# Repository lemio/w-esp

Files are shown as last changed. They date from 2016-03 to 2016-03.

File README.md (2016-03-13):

# w-esp
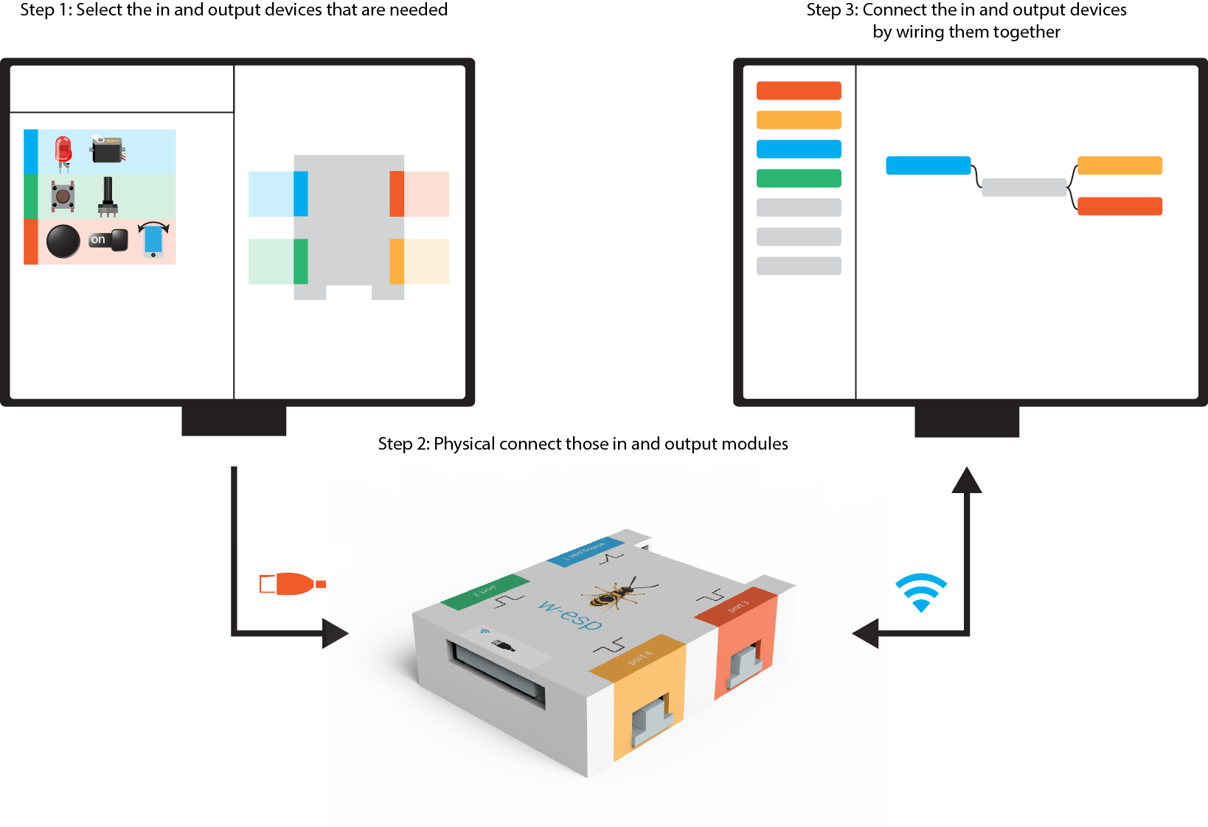
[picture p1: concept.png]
W-esp enable students to play with the internet of things


 The W-esp is a toolkit that enables the first and second year students of secondary education to connect sensors and actuators to the internet and create interactive systems that use the internet of things. This could be for example a locker that is controlled by your mobile phone, a system that prevent your grandmother from sleepwalking, automatically feeds the chickens… the sky is the limit.

The process of building such a system consists of three steps. First the w-esp needs to know which sensors and actuators are connected to the board, by using a drag and drop system [see step 1] the user can drop the in- and output icons on the different ports. After doing that the hardware needs to be physically connected to the w-esp [step 2]. Now the students can open a flow chart programming system based on Node-red(IBM) [step 3] in which they can flows consisting of input blocks, output blocks and processing blocks.

I learned very early the difference between knowing the name of something and knowing something. – R.P. Feynman

In this way the children can learn about programming concepts, without the need to learn difficult syntaxes and languages, they also can use the internet (social media, mobile phone) as in or output and in this way create awesome projects.

#Getting started (software)

* Update the firmware on your w-esp (see the folder final_firmware_esp)
* Put the LUA code on your esp board (see the folder lua_code)
* Donwload node.js https://nodejs.org/en/
* Run node-red (see folder w-esp-node-red)
* Open the chrome app (see folder w-esp-chrome-app)
* Find your IP adress (start; type cmd and press enter) -> type ipconfig in the command line
* Fill in the connection details in the chrome app
* Connect the blocks you want to use
* Hit launch node-red
* Click on the right-top
* Click import from clipboard
* Start playing with node-red

# Getting started hardware

* Getting the parts (see folder hardware)
* Solder or make a breadboard setup for your components
* 3D print a casing (optional)
* print a sticker for the port mapping (optional)

# Future

* Live debugging (in a visual way), the threshold to use the debug function is still to high. Ideally you want to see the messages, and their values flowing through the wires. Also the icons of the sensors/actuators could show their status (in a way that you can really see the servo moving, and the pushbutton being pushed in the software)
* Larger icons and corresponding color in node-red, also connecting the visual styles of node-red and w-esp more. The w-esp software and the node-red software are still two different things, they should merge to one system node-red should also communicate what is connected to the w-esp hardware.
* More decent firmware (native c++), the current firmware is based on LUA, because it was easier to write it in LUA. But when moving to production the firmware should be based on c/c++ because then the hardware could be used optimal and memory issues are history.
* Integration with other (flow chart/data logging) online services, for example If this than that (a cloud service for connecting different application programming interfaces with each other and Thingspeak (data logging service).
* More solid (and less open) course material, teachers want to have something to fall back at. Perhaps this could be in combination with inspiration on different design briefs for the teacher.
* Focus more on how girls relate to this subject, using textiles/more context/less hands-on.
* Try to use the hardware that is already in the school (most physics classes have banana connectors and hardware that can be connected with those banana wires.
* More hardware to connect to the w-esp (and perhaps an advanced toolkit) for example klikaanklikuit remote controlled relays, distance sensors, speakers, light sensor, temperature sensor, touch sensor.
* Running a pilot with different schools to detect practical problems.

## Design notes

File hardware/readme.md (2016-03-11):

#Hardware

##3D printed parts

- bottom_w-esp.stl
- top_w-esp.stl

Those parts are printed in a FabLab in Eindhoven. I also added the source files *.prt the parts are designed in Siemens NX. 

##Casing sticker

This sticker is printed on a laser-jet printer, they are cut with a knife ;)

##Electronics

See the fritzing file for the schematic

(with pricing in euro's, estimate)

| Object 	| EU |
| ---	| --:|
| ESP chip |8,00|
| PCB cost |1,00|
| Connectors |0,80|
| Screw terminals |1,00|
| Casing |5,00|
| servo |3.50|
| led |0,50|
| pushbutton |0,50|
| slider |0,50|
| Packaging |2,00|
| USB cable |1,00|
| Other/unexpected  |2,00|

NodeMCU can for example be found:
* (http://www.ebay.com/sch/i.html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)
* (http://www.dx.com/p/nodemcu-esp8266-esp-12-deleopment-board-lua-wi-fi-module-w-built-in-antennas-385190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)

So in total for less than 30 euro's

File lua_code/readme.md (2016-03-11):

#Lua code

First update the firmware on the ESP chip (see the firmware section), this is needed to make sure there is enough heap space for the program to run.

Open the files in ESPlorer or another LUA editor
https://github.com/4refr0nt/ESPlorer

1. Upload the files to the ESP chip
2. Compile those files (except the conf.lua files)
3. Delete the not compiled versions from the chip (except the conf.lua files)

## Overview of files
### init
(Initializes the program, also makes sure that you can stop the other code from running by connecting pin 4 to the ground)

### start
"start" (requires all the other files, is the main program, it deals with the WIFI, makes all devices are added and keeps the websocket alive, or restarts the connection)

### devices
(Takes care of the devices that are plugged or unplugged in the software, makes sure (PWM) ports are configured in the right way, and sets the triggers for the inputs)

| Type | DeviceType |
| --- | ---:|
| NO_CONNECTION | -1|
| ANALOG_DEVICE | 0|
| ANALOG_OUTPUT | 1|
| DIGITAL_INPUT | 2|
| SERVO_OUTPUT | 3|

**deleteDevice** (port (port on the w-esp 1-4; integer), deviceType (type of device 0-3; integer)

Deletes the device, disable the pwm/trigger/analog behavior

**addDevice** (port (port on the w-esp 1-4; integer), deviceType (type of device 0-3; integer)

Adds the device, enables the pwm/trigger/analog behavior 

**getDevices** ()

Prints the current devices connected to the w-esp in this format:
`DEVICES&1&(P1)&2&(P2)&3&(P3)&4&(P4)&`
where (Px) is replaced with the deviceType

**setDevices** ()

Save the current global ports variable in the devices.conf.lua file

### websocket

**ws_recieve** (conn (.net connection), payload (string))

Handle the recieved messages

**range** (val; integer, max; integer) 

Fit a value within a range from (0 to max)

**ws_begin** (host (domain name or IP string), path (string),port (string))

Start a .net connection with the host

**ws_start** (conn (.net connection), IP (String))

Setup a websocket connection with the conn

**ws_keep_alive** () 

Send ping (keep alive) message; it should give back a pong message (still alive)

**ws_send** (msg) 

Send a websocket message, with a specific content

**ws_close** () 

Close the websocket client

### settings

**changeWifi** (ssid,password)

Change the wifi network and password

**readWifi** ()

Read the current wifi.conf.lua settings and print those (over the serial port) in this format:

`SSID&(x)&PASS&(x)`

**connectWifi** ()

Connect to the selected wifi network

**changeConnection** (host,path,port)

Change the connection details (for the websocket server)

**readConnection** ()

Read the connection details and print those (over the serial port) in this format:

`HOST&(x)&PATH&(x)&PORT&(x)`

**startConnection** ()

Start a connection with the websocket server

**closeConnection** ()

Close the connection with the websocket server (Not implemented)

(All the functions for changing settings from the chrome app, connection and wifi)

## Config files

### wifi.conf.lua

File with the wifi settings, in this format:

```ini
ssid="nameofssid"
password="passwordofssid"```

### connection.conf.lua

File with the server settings, in this format:

```ini
host = "my.web.server.com"
path = "/my/path/for/the/websocket/"
port = 80```

(host could also be an (local) IP adress)

### devices.conf.lua

File with the devices connected to the w-esp, in this format:

```ini
ports = {-1,-1,-1,-1}```

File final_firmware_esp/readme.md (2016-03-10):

If you just want to upload it to the ESP chip:

Use https://github.com/nodemcu/nodemcu-flasher

If you want to create your own firmware:

Built using NodeMCU-build

http://nodemcu-build.com/

Selected modules:
adc, file, gpio, net, node, pwm, tmr, uart, wifi

And choose integer for download

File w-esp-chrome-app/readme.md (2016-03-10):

Go to settings in Google Chrome

Go to extensions

Select Load unpacked extension

-> Select the w-esp-chrome-app folder

When you browse to apps (chrome://apps/ , in my case in the left top corner) the w-esp app should be visible. First connect the w-esp and afterwards start the app. This app uses the Serial port and might not properly close it, so if you want to use ESPlorer afterwards, unplug the w-esp and plug it in. 

The app still needs a lot of documentation and more proper file index...

#references

The design of the components is from fritzing:
Creative Commons Attribution-ShareALike 3.0 Unported

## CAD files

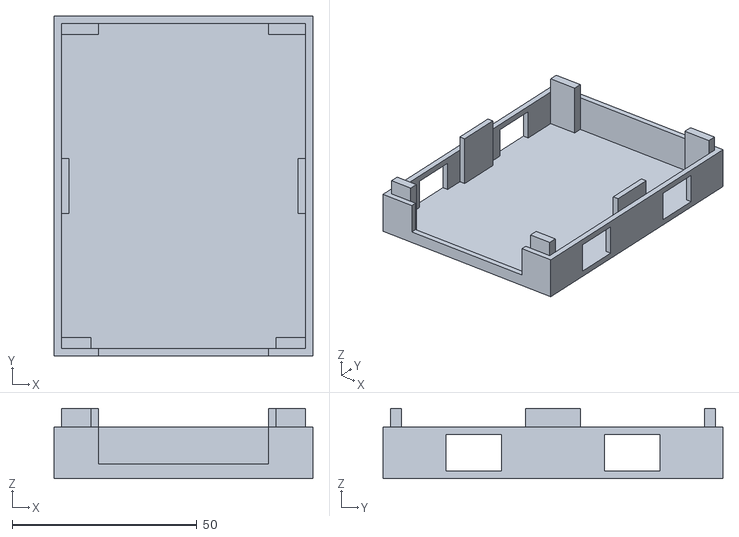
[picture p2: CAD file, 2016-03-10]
hardware/bottom_w-esp.stl
70.0 x 92.0 x 19.0

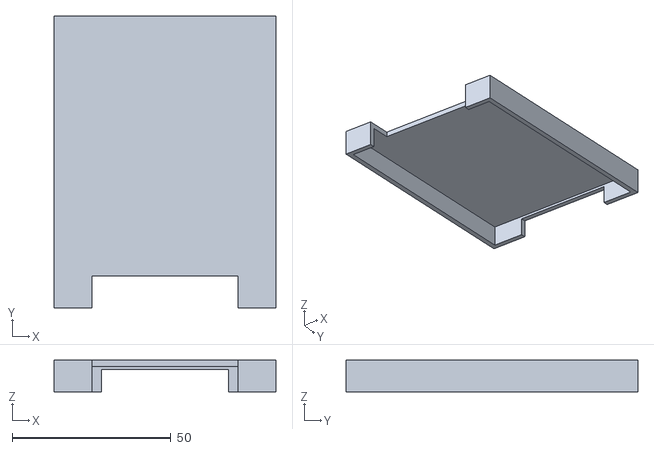
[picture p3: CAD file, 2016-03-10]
hardware/top_w-esp.stl
70.0 x 92.0 x 10.0

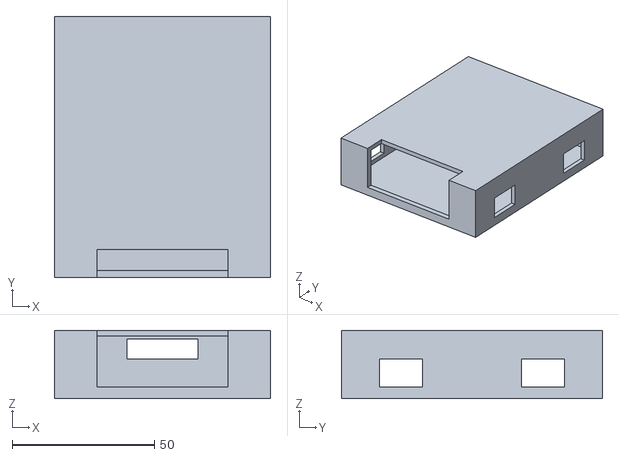
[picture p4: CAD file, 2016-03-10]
hardware/w-esp.stl
76.0 x 92.0 x 24.0

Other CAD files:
hardware/assembly_w-esp.prt
hardware/casing_w-esp.prt
hardware/electronics.prt

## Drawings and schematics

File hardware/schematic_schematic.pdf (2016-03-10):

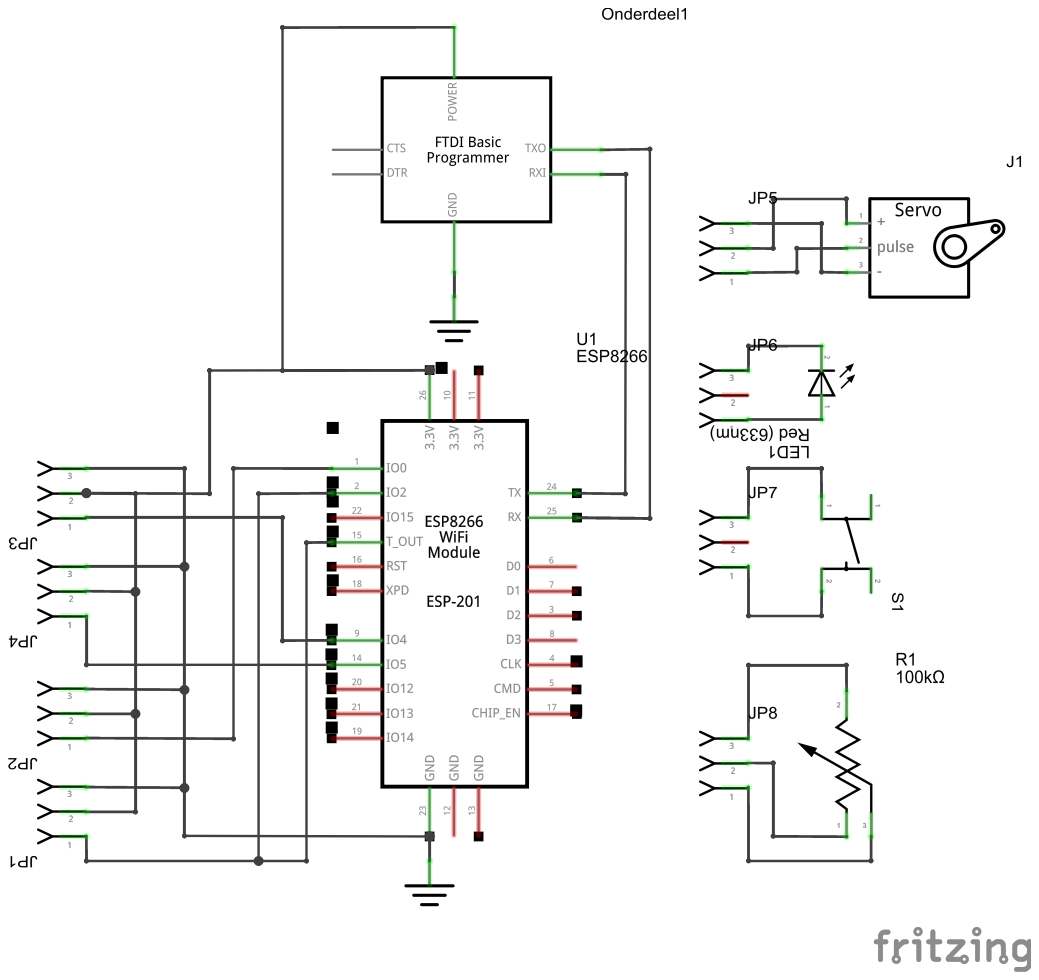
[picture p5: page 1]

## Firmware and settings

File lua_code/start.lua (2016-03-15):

require "devices"
require "websocket"
require "settings"
keep_alive = 0
connectWifi()
tmr.alarm(6, 200, 1, function ()
    if (wifi.sta.status() == 5) then
    gpio.write(0,gpio.HIGH)
        print("WESP_WIFI_CONNECTED")
        tmr.alarm(6, 100, 0, function ()
            startConnection()
            dofile("devices_conf.lua")
            addDevice(1,ports[1],true)
            addDevice(2,ports[2],true)
            addDevice(3,ports[3],true)
            addDevice(4,ports[4],true)
            tmr.alarm(6,2000,1, function ()
            gpio.write(0,gpio.HIGH)
                if (keep_alive > 3) then
                    keep_alive = 0
                    ws_close()
                    ws_begin(host,path,port)
                    --reconnect
                end
                keep_alive = keep_alive + 1
                ws_keep_alive()
            end
            )
        end
        )
    end
end
)

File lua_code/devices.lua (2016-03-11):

function deleteDevice(port, deviceType)
    local ports_to_pin = {4,3,2,1}
    if (deviceType == 0) then
    -- ANALOG DEVICE
    tmr.stop(0)
    elseif  (deviceType == 1) then
    -- ANALOG OUTPUT (LED)
    pwm.stop(ports_to_pin[port])
    elseif  (deviceType == 2) then
    -- DIGITAL INPUT
    
    elseif  (deviceType == 3) then
    -- SERVO OUTPUT
    pwm.stop(ports_to_pin[port])
    end
    ports[port] = -1
    setDevices()
end
function addDevice(port, deviceType)
    deleteDevice(port,deviceType)
    local ports_to_pin = {4,3,2,1}
    ports[port] = deviceType
    if (deviceType == 0) then
    -- ANALOG DEVICE
    tmr.alarm(0, 1000, 1, function() 
    value = adc.read(0)
    ws_send("A1" .. value)
    end )
    elseif  (deviceType == 1) then
    -- ANALOG OUTPUT (LED)
    pwm.setup(ports_to_pin[port],100,1000)
    pwm.start(ports_to_pin[port])
    elseif  (deviceType == 2) then
    -- DIGITAL INPUT
    gpio.mode(ports_to_pin[port],gpio.INT, gpio.PULLUP)
    gpio.trig(ports_to_pin[port], "both", function(level) if (level == 0) then
                                            ws_send("D" .. port .. "1")
                                            else
                                            ws_send("D" .. port .. "0")
                                            end
                                            end)
    --gpio.trig(ports_to_pin[port], "up"  , ws_send("D" .. port .. "1"))
    elseif  (deviceType == 3) then
    -- SERVO OUTPUT
    pwm.setup(ports_to_pin[port],100,40)
    pwm.start(ports_to_pin[port])
    end
    setDevices()
    print("DEVICE (".. port .. " " .. deviceType);
end
function getDevices()
    dofile("devices_conf.lua")
    print("DEVICES&1&" .. ports[1] .. "&2&" .. ports[2] .. "&3&" .. ports[3] .. "&4&" .. ports[4] .. "&")
end
function setDevices()
    
    file.open("devices_conf.lua","w+");
    local w = file.writeline
    w("ports = {"..ports[1] ..","..ports[2] ..",".. ports[3] ..",".. ports[4] .."}");
    file.close();
end
------------------------------

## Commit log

2016-03-10 w-esp web app (for mobile devices, behind the QR code)
2016-03-10 Added hardware documentation
    [assembly_w-esp.prt, bottom_w-esp.stl, casing_w-esp.prt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]
2016-03-11 Updated BOM
2016-03-11 BOM update
2016-03-15 Fixed reference to devices_conf
    [start.lua]
